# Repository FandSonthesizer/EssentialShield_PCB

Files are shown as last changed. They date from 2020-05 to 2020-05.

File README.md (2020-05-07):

# EssentialShield_PCB
STM32F103c based shield for digital and analog input and output

This shield is a very powerful tool for multiple purposes. It can be used in all kinds of applications, where you 
need analog input and analog output as well as digital in- and output. We use it very much in our audio applications.
It is prepared for a display and and encoder and it can receive and send MIDI signals.

Specs: 
- Based on a cheap 'Blue-Pill' stm32f103c shield.
- Up to 4 Analog outputs in the range of 0-10V
- 8 analog /digital inputs (0-3.3V)
- 4 Digital outputs (0-5V)
- 3 digital inputs (0-3.3V)
- 1 Gate/Trigger input (0-10V)
- Midi in/out
- Connector for KY 040 Encoder
- Connector for SPI OLED display e.g. 128x64 pixel black and white OLED
- Connector for USB to TTL adapter
- Eurorack power connector (2 x 8 pin)

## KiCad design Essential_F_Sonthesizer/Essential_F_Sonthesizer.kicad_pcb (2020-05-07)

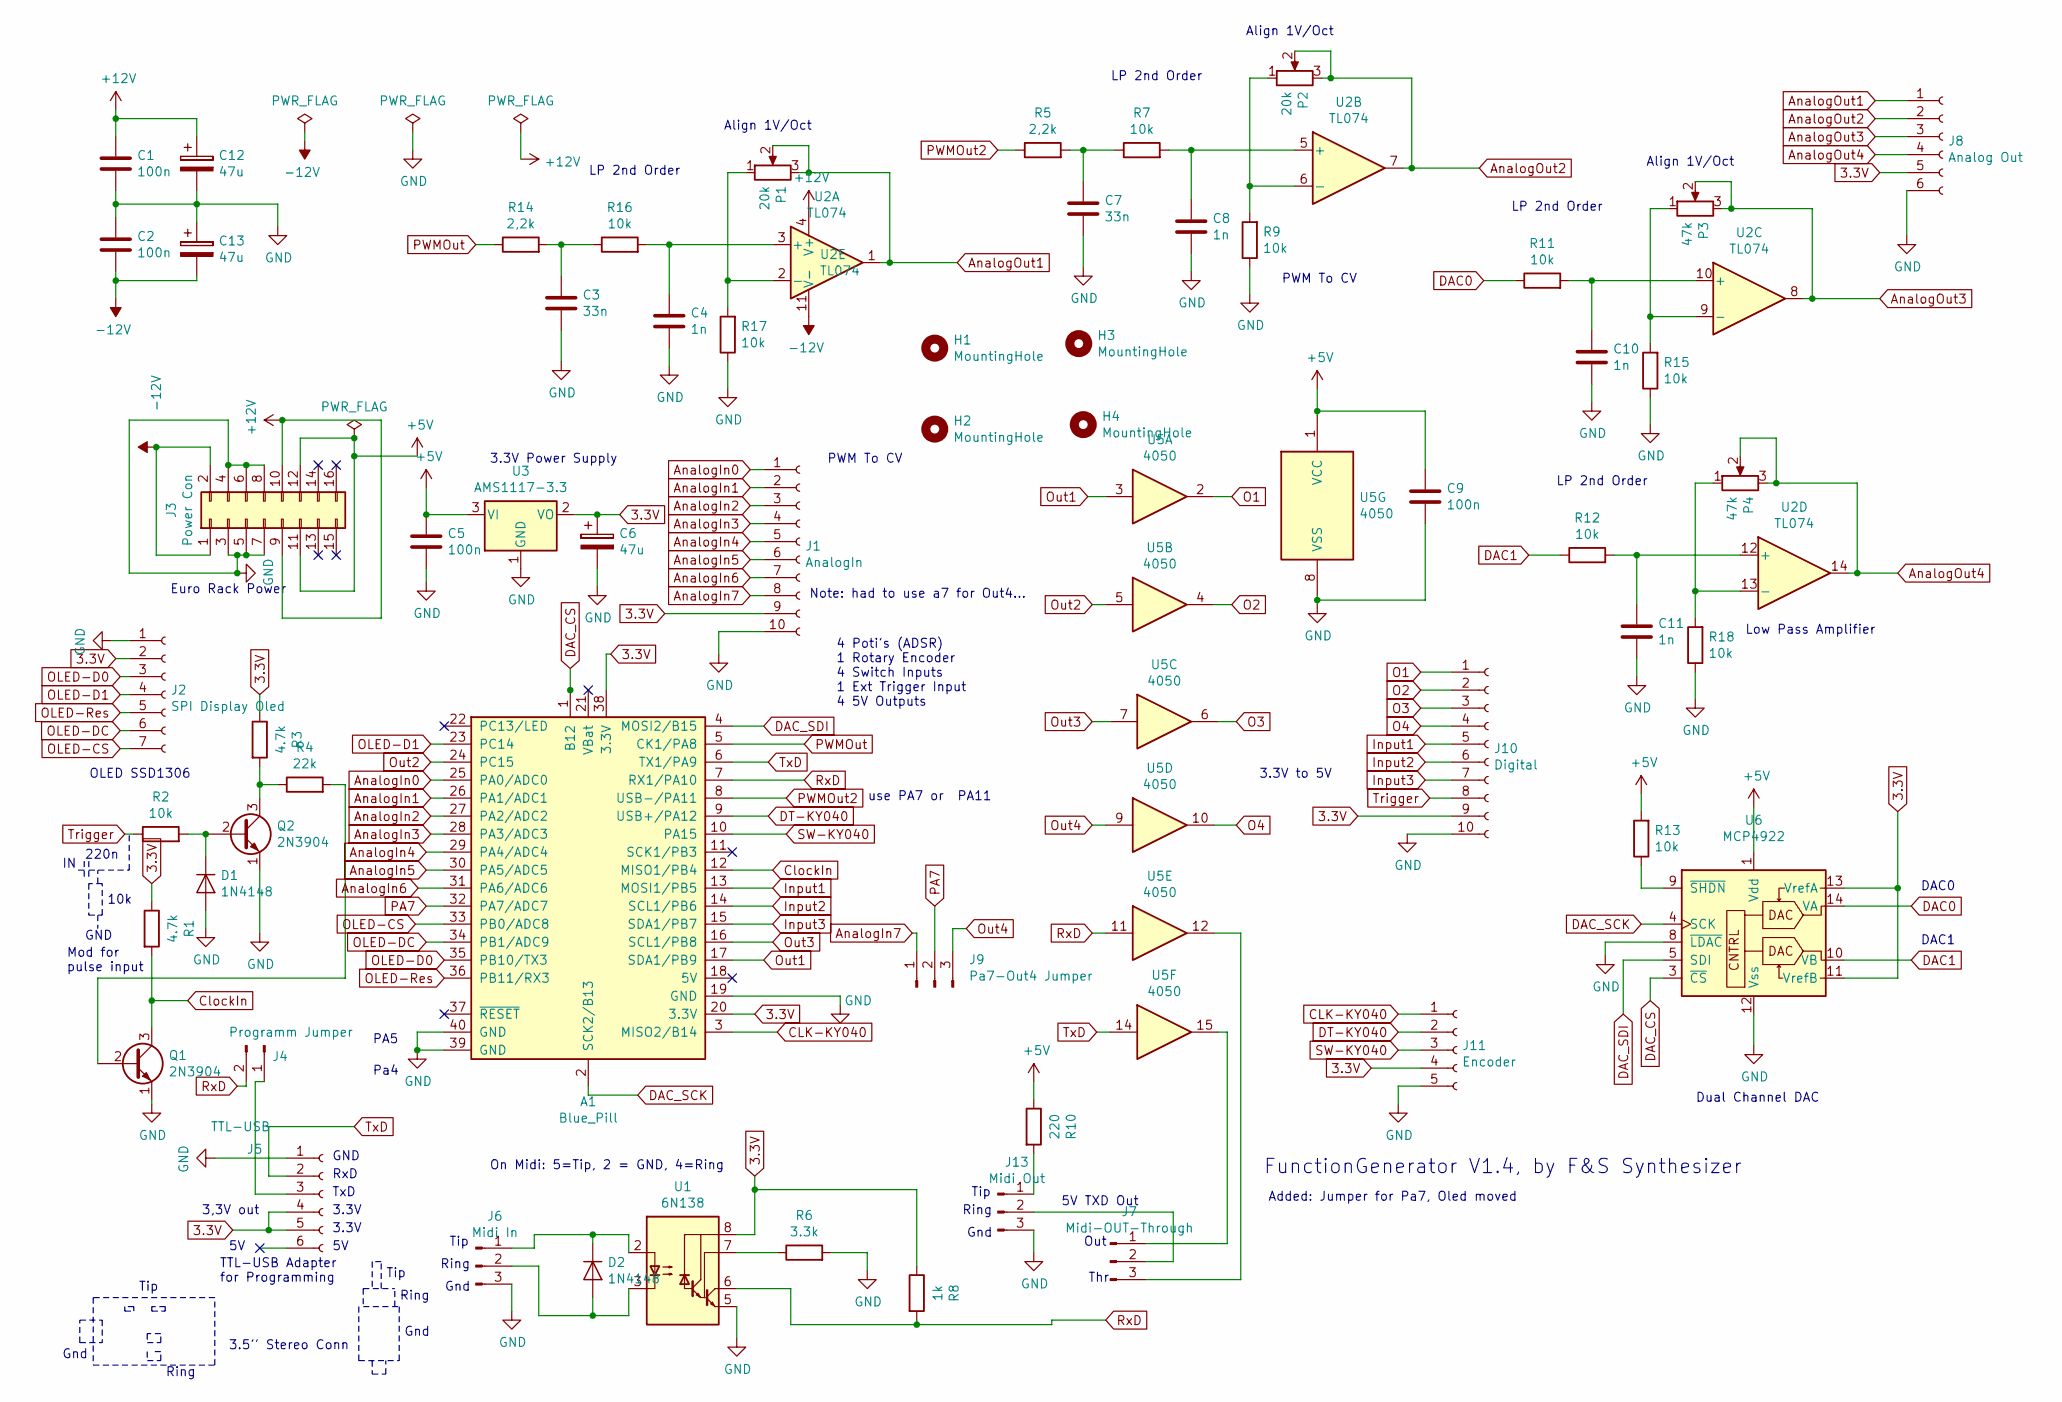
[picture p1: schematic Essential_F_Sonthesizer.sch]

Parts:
A1: Blue_Pill; DIP-40_W15.24mm_Socket_LongPads
C1, C2, C5, C9: 100n; Kondensator_Keramik
C3, C7: 33n; Kondensator_Keramik
C4, C8, C10, C11: 1n; Kondensator_Keramik
C6, C12, C13: 47u; Elko_D6.3mm_P2.50mm
D1, D2: 1N4148; Diode_Horizontal
H1, H2, H3, H4: MountingHole; MountHole
J1: AnalogIn; PinHeader_1x10_P2.54mm_Vertical
J2: SPI Display Oled; PinHeader_1x07_P2.54mm_Vertical
J3: Power Con; PinHeader_2x08_P2.54mm_Vertical
J4: Programm Jumper; Stift_x02
J5: TTL-USB; PinHeader_1x06_P2.54mm_Vertical
J6: Midi In; Stift_0x3
J7: Midi-OUT-Through; Stift_0x3
J8: Analog Out; PinHeader_1x06_P2.54mm_Vertical
J9: Pa7-Out4 Jumper; Stift_0x3
J10: Digital; PinHeader_1x10_P2.54mm_Vertical
J11: Encoder; PinHeader_1x05_P2.54mm_Vertical
J13: Midi Out; Stift_0x3
P1, P2: 20k; Trimmer_Vertical
P3, P4: 47k; Trimmer_Vertical
Q1, Q2: 2N3904; TO-92_Wide
R1, R3: 4.7k; Widerstand_liegend
R2, R7, R9, R11, R12, R13, R15, R16, R17, R18: 10k; Widerstand_liegend
R4: 22k; Widerstand_liegend
R5, R14: 2,2k; Widerstand_liegend
R6: 3.3k; Widerstand_liegend
R8: 1k; Widerstand_liegend
R10: 220; Widerstand_liegend
U1: 6N138; DIP-8_W7.62mm_LongPads
U2: TL074; DIP-14_W7.62mm_Socket_LongPads
U3: AMS1117-3.3; SOT-223-3Lead_TabPin2
U5: 4050; DIP-16_W7.62mm_LongPads
U6: MCP4922; DIP-14_W7.62mm_Socket_LongPads

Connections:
3.3V: A1.20 (3.3V), A1.38 (3.3V), C6.1, J1.9, J2.2, J5.4, J5.5, J8.5, J10.9, J11.4, R1.1, R3.1, R8.1, U1.8 (VCC), U3.2 (VO), U6.11 (VrefB), U6.13 (VrefA)
+5V: C5.1, C9.1, J3.11, J3.12, R10.1, R13.2, U3.3 (VI), U5.1 (VCC), U6.1 (Vdd)
+12V: C1.1, C12.1, J3.9, J3.10, U2.4 (V+)
-12V: C2.2, C13.2, J3.1, J3.2, U2.11 (V-)
AnalogIn0: A1.25 (PA0/ADC0), J1.1
AnalogIn1: A1.26 (PA1/ADC1), J1.2
AnalogIn2: A1.27 (PA2/ADC2), J1.3
AnalogIn3: A1.28 (PA3/ADC3), J1.4
AnalogIn4: A1.29 (PA4/ADC4), J1.5
AnalogIn5: A1.30 (PA5/ADC5), J1.6
AnalogIn6: A1.31 (PA6/ADC6), J1.7
AnalogIn7: J1.8, J9.1
AnalogOut1: J8.1, P1.2, P1.3, U2.1
AnalogOut2: J8.2, P2.2, P2.3, U2.7
AnalogOut3: J8.3, P3.2, P3.3, U2.8
AnalogOut4: J8.4, P4.2, P4.3, U2.14
CLK-KY040: A1.3 (MISO2/B14), J11.1
ClockIn: A1.12 (MISO1/PB4), Q1.3 (C), R1.2
DAC0: R11.1, U6.14 (VA)
DAC1: R12.1, U6.10 (VB)
DAC_CS: A1.1 (B12), U6.3 (~CS)
DAC_SCK: A1.2 (SCK2/B13), U6.4 (SCK)
DAC_SDI: A1.4 (MOSI2/B15), U6.5 (SDI)
DT-KY040: A1.9 (USB+/PA12), J11.2
GND: A1.19 (GND), A1.39 (GND), A1.40 (GND), C1.2, C2.1, C3.2, C4.2, C5.2, C6.2, C7.2, C8.2, C9.2, C10.2, C11.2, C12.2, C13.1, D1.2 (A), J1.10, J2.1, J3.3, J3.4, J3.5, J3.6, J3.7, J3.8, J5.1, J6.3, J8.6, J10.10, J11.5, J13.3, Q1.1 (E), Q2.1 (E), R6.2, R9.1, R15.1, R17.1, R18.1, U1.5 (GND), U3.1 (GND), U5.8 (VSS), U6.8 (~LDAC), U6.12 (Vss)
Input1: A1.13 (MOSI1/PB5), J10.5
Input2: A1.14 (SCL1/PB6), J10.6
Input3: A1.15 (SDA1/PB7), J10.7
unnamed: C3.1, R14.2, R16.1
unnamed: C4.1, R16.2, U2.3 (+)
unnamed: C7.1, R5.2, R7.1
unnamed: C8.1, R7.2, U2.5 (+)
unnamed: C10.1, R11.2, U2.10 (+)
unnamed: C11.1, R12.2, U2.12 (+)
unnamed: D1.1 (K), Q2.2 (B), R2.2
unnamed: D2.1 (K), J6.1, U1.2 (C1)
unnamed: D2.2 (A), J6.2, U1.3 (C2)
unnamed: J4.1, J5.3
unnamed: J7.1, U5.15
unnamed: J7.3, U5.12
unnamed: J13.1, R10.2
unnamed: J7.2, J13.2
unnamed: P1.1, R17.2, U2.2 (-)
unnamed: P2.1, R9.2, U2.6 (-)
unnamed: P3.1, R15.2, U2.9 (-)
unnamed: P4.1, R18.2, U2.13 (-)
unnamed: Q1.2 (B), R4.2
unnamed: Q2.3 (C), R3.2, R4.1
unnamed: R6.1, U1.7 (VO1)
unnamed: R13.1, U6.9 (~SHDN)
O1: J10.1, U5.2
O2: J10.2, U5.4
O3: J10.3, U5.6
O4: J10.4, U5.10
OLED-CS: A1.33 (PB0/ADC8), J2.7
OLED-D0: A1.35 (PB10/TX3), J2.3
OLED-D1: A1.23 (PC14), J2.4
OLED-DC: A1.34 (PB1/ADC9), J2.6
OLED-Res: A1.36 (PB11/RX3), J2.5
Out1: A1.17 (SDA1/PB9), U5.3
Out2: A1.24 (PC15), U5.5
Out3: A1.16 (SCL1/PB8), U5.7
PA7: A1.32 (PA7/ADC7), J9.2
PWMOut: A1.5 (CK1/PA8), R14.1
PWMOut2: A1.8 (USB-/PA11), R5.1
RxD: A1.7 (RX1/PA10), J4.2, R8.2, U1.6 (VO2), U5.11
SW-KY040: A1.10 (PA15), J11.3
Trigger: J10.8, R2.1
TxD: A1.6 (TX1/PA9), J5.2, U5.14

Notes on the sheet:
Euro Rack Power
Align 1V/Oct
PWM To CV
FunctionGenerator V1.4, by F&S Synthesizer
Tip
Gnd
Ring
On Midi: 5=Tip, 2 = GND, 4=Ring
LP 2nd Order
OLED SSD1306
TTL-USB Adapter for Programming
5V TXD Out
Thr
Out
3.3V to 5V
use PA7 or PA11
4 Poti's (ADSR) 1 Rotary Encoder 4 Switch Inputs 1 Ext Trigger Input 4 5V Outputs
PA5
Pa4
3,3V out
DAC0
DAC1
Dual Channel DAC
3.3V Power Supply
Low Pass Amplifier
3.5'' Stereo Conn
GND
RxD
TxD
3.3V
Note: had to use a7 for Out4...
Added: Jumper for Pa7, Oled moved
10k
220n
Mod for pulse input

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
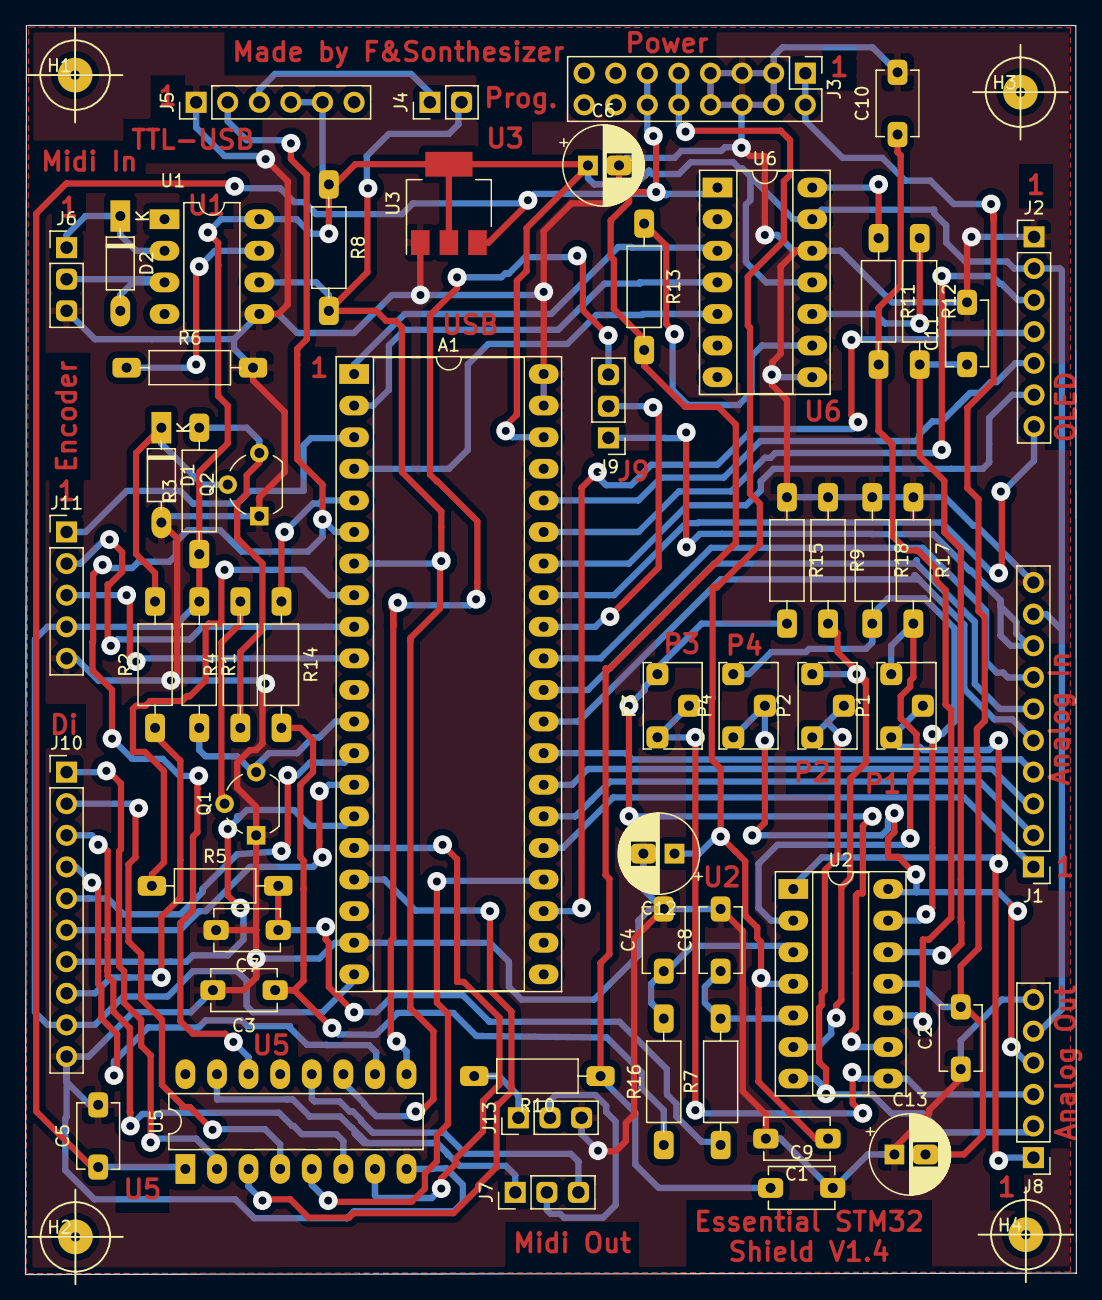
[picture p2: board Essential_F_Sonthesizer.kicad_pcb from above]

Board: 2 copper layers, 84.5 x 100.4 mm, 61 parts (0 on the bottom side), 69 nets.
